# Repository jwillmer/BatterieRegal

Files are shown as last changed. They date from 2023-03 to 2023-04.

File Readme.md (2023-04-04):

# Batterie Regal

Eine kurze Anleitung zum Bau eines Regals aus Aluminiumprofilen zur Unterbringung von Batterie Racks.

## Design Bilder

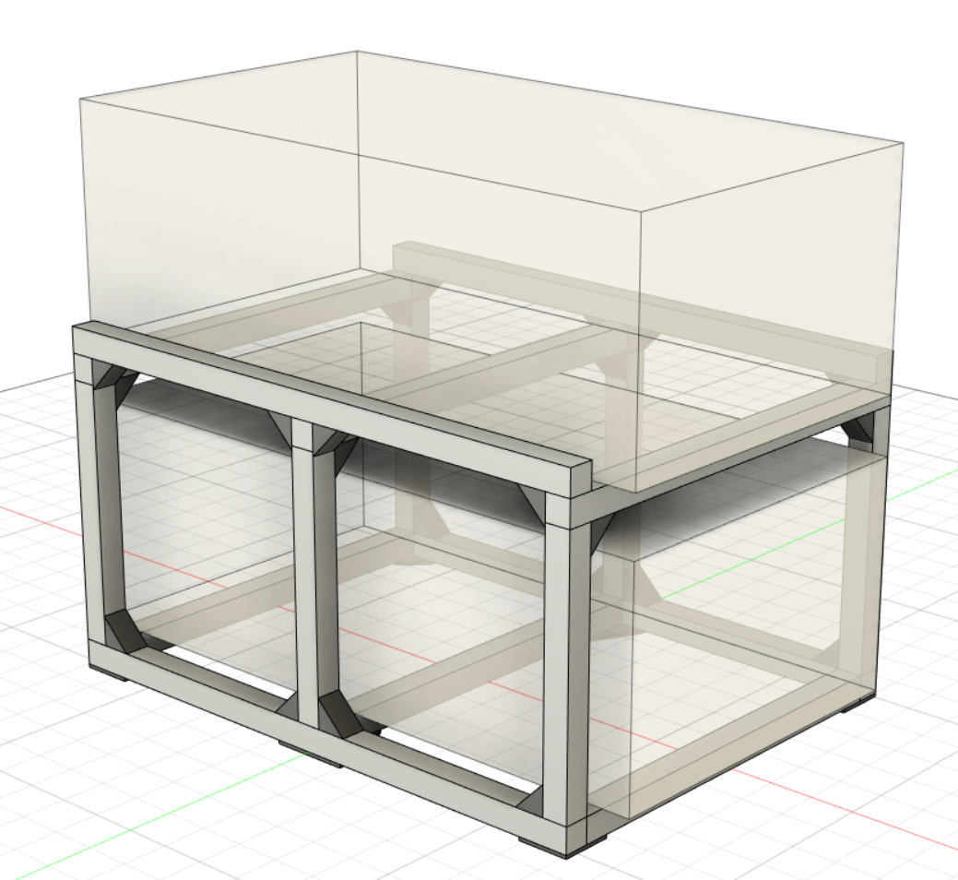
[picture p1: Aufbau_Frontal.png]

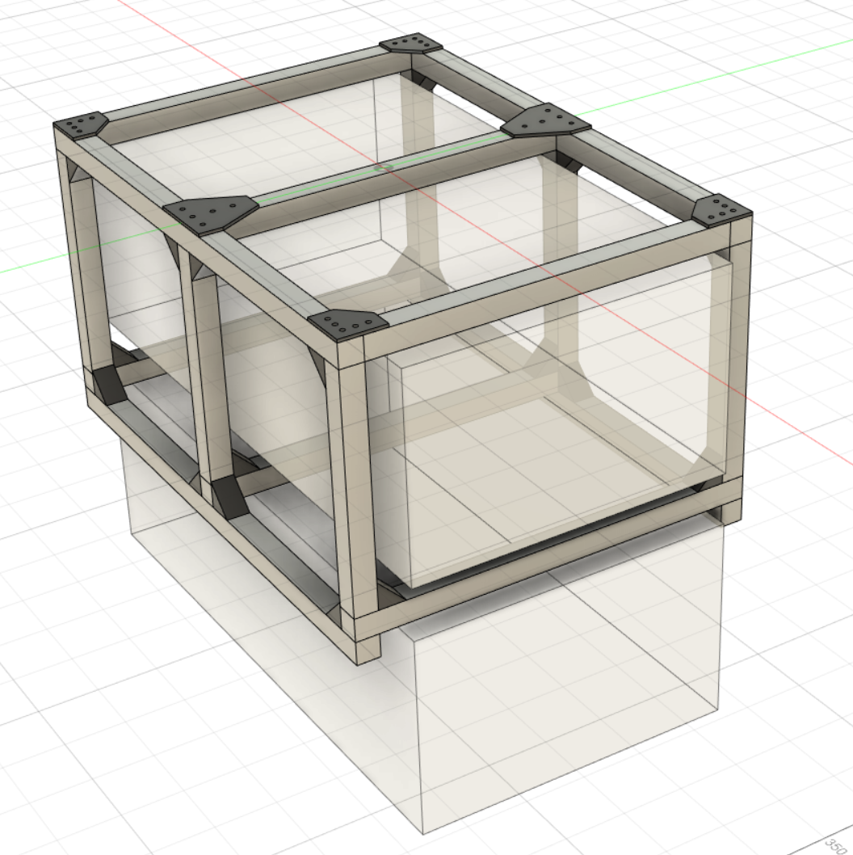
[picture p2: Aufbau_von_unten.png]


## Darstellung 

Die Autodesk Datei kann [hier heruntergeladen][f3d] werden oder direkt im Browser gerendert werden: [Autodesk Gallery][a360]

## Materialkalkulation

Ein Batterie Rack soll ungefähr 100 kg schwer sein. Aufgeteilt auf drei Querstreben sind dies ungefähr 350 Newton pro Strebe. Die 3 cm Aluminiumprofile sollten dieses Gewicht also gut halten können.

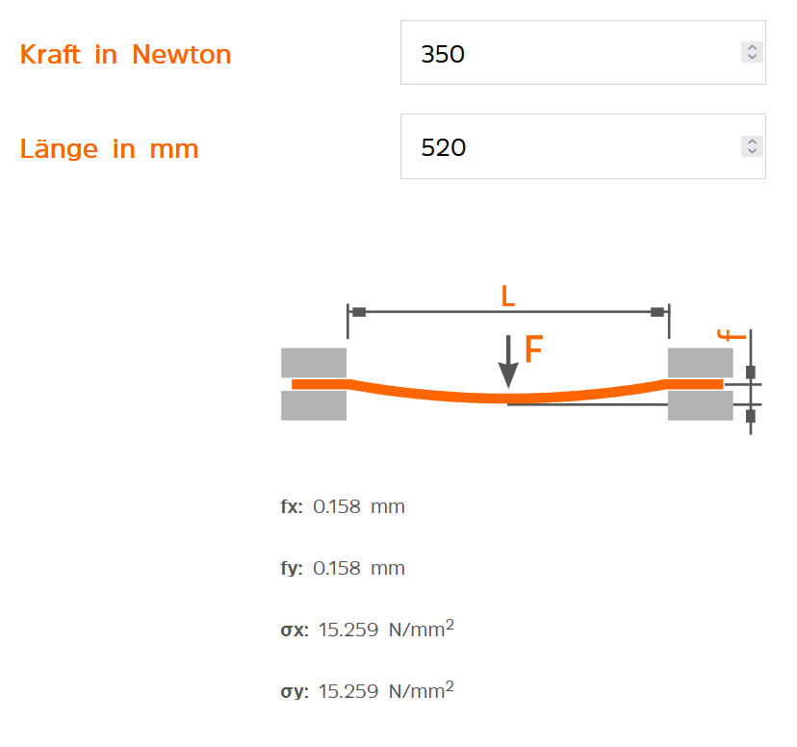
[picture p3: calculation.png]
Materialkalkulation


## Materialliste

Ich habe bei folgender Firma bestellt: [myaluprofil.de][myaluprofil]. Der Warenwert war 120.- Euro plus Versand. 

### Achtung
Profiltype `leicht` war ein Fehler. Leicht bedeutet, dass das ganze Zubehör eine Spezialgröße benötigt und die untere liste nicht passt. Also darauf achten nicht `leicht` zu kaufen.

| Anzahl | Artikel | Type  | Länge  |
|---|---|---|---|
| 2 | Aluminiumprofil 30x30 Nut 6 I-Typ Leicht | 2N180 | 700 mm |
| 3 | Aluminiumprofil 30x30 Nut 6 I-Typ Leicht | 3N | 460 mm |
| 2 | Aluminiumprofil 30x30 Nut 6 I-Typ Leicht | 1N | 300 mm |
| 4 | Aluminiumprofil 30x30 Nut 6 I-Typ Leicht | 2N90  | 300 mm |
| 2 | Aluminiumprofil 30x30 Nut 6 I-Typ Leicht | 2N90  | 520 mm |
| 1 | Aluminiumprofil 30x30 Nut 6 I-Typ Leicht | 1N | 520 mm |
| 2 | Aluminiumprofil 30x30 Nut 6 I-Typ Leicht | 3N | 700 mm |

Folgendes habe ich direkt in China bestellt via [Aliexpress][aliexpress]. Der Warenwert war 85.- Euro. Bitte achte auf die Beschreibung, manchmal sind es Sets die hier gelistet sind.

| Bild | Anzahl | Beschreibung |
|---|---|---|
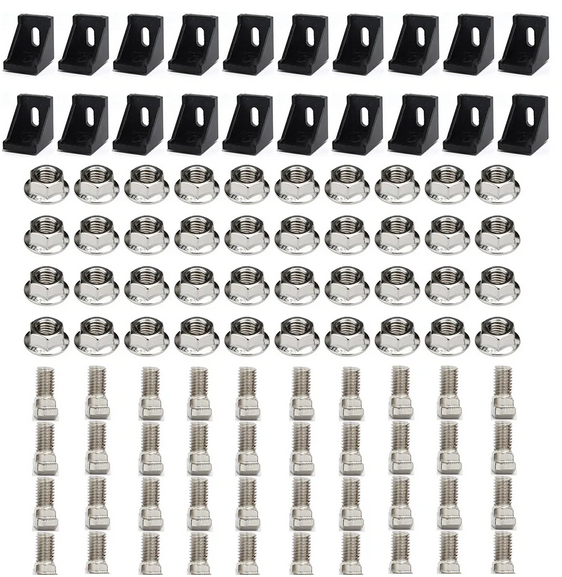
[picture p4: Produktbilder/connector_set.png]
Aluminum Profile Connector Set
|  | 1 | 3030 Aluminum Profile Connector Set: 20pcs 3030 Corner Bracket + 40pcs M6 x 16mm T Bolt Screws + 40pcs M6 Hex Flange Nuts |
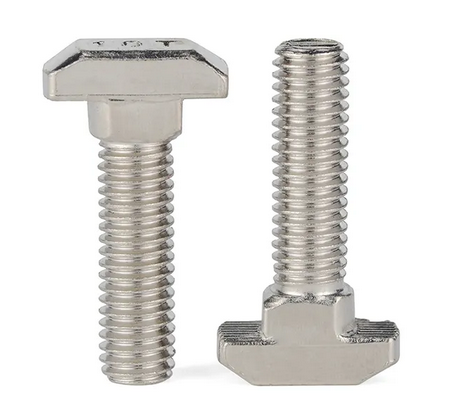
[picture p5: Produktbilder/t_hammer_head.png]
M6 T Hammer Head Bolt
|  | 4 | M6 T Hammer Head T Bolt Aluminum Connector T head bolts Screws for 30 Aluminum Profiles |
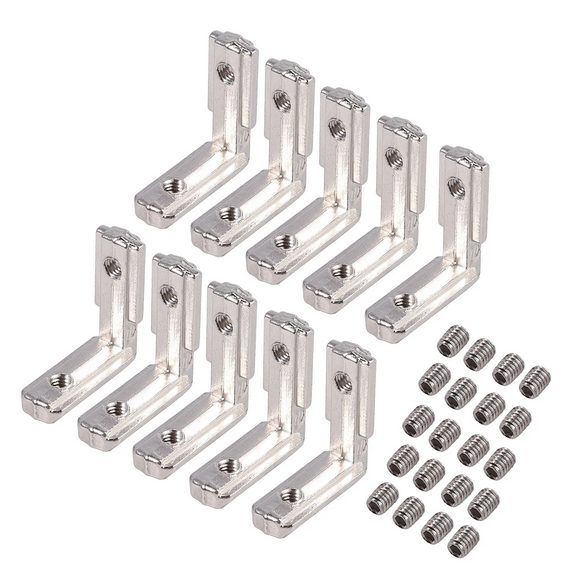
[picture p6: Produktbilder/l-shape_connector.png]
T Slot L-Shape Corner Connector
|  | 1 | 10pcs T Slot L-Shape Interior Corner Connector Joint Bracket 3030 with screws Aluminum Profile Extrusion Connector |
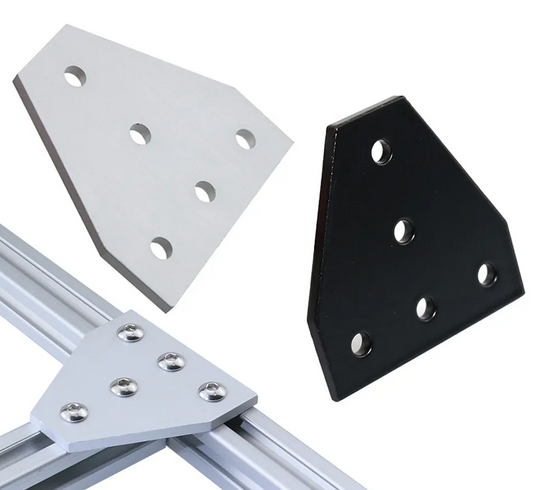
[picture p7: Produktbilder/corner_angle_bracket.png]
Corner Angle Bracket Joint
|  | 2 | Strong Corner Angle Bracket Connection Joint Strip Board for V-slot Aluminum Profile 3030 with 5 holes |
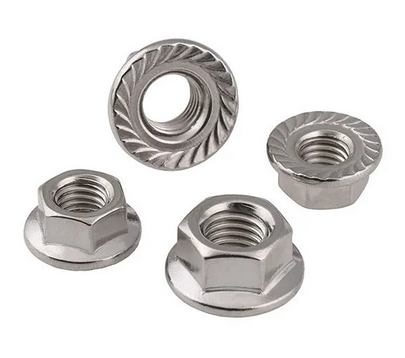
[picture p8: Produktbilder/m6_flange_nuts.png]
Flange Nuts M6
|  | 1 | 50pcs DIN6923 Flange Nuts M6 304 Stainless Steel Hex Lock Self-Locking Metric Thread Serrated Nut |
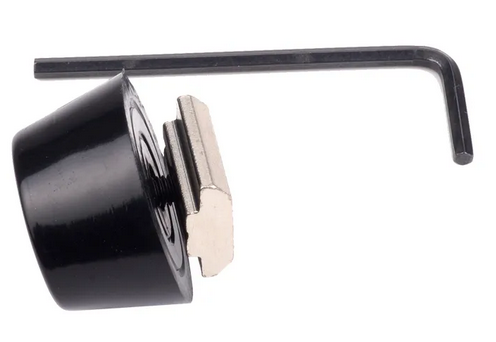
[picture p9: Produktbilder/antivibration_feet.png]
Antivibration Feet
|  | 1 | 8 Sets Antivibration Feet Anti-vibration Rubber Landing Mat Feet For Prusa i3 MK3 Kit For 3030 Profile 3d Printer Parts |
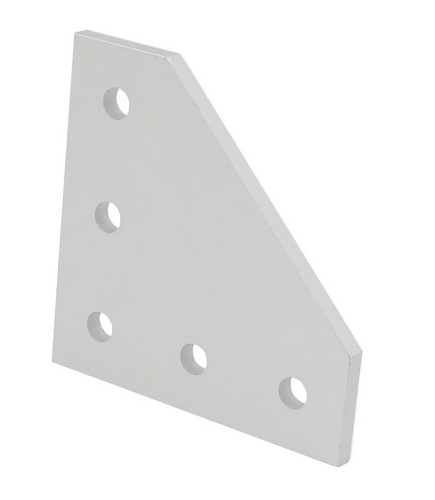
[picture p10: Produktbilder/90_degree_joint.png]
90 Degree Joint Board
|  | 4 | 3030 with 5 hole L T type 90 Degree Joint Board Plate Corner Angle Bracket Connection for Aluminum Profile |

[myaluprofil]: https://www.myaluprofil.de
[aliexpress]: https://www.aliexpress.com
[f3d]: BatteryRackV4.f3d
[a360]: https://a360.co/3yKJpqY

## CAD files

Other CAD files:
BatteryRackV4.f3d

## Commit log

2023-03-16 project upload
    [Battery Rack v4.f3d, Battery Rack v4.stl]
2023-03-16 fix file links
    [BatteryRackV4.f3d, BatteryRackV4.stl]
2023-03-16 render link
    [BatteryRackV4.stl]
